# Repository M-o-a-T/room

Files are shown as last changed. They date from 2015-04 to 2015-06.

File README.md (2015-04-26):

# Room controller

Initially planned for controlling a radiator, this mutated into a generic
room controller schematic, featuring

* ATmega 168 controller
* two 1wire slave interfaces
* one I²C interface
* two 24V outputs
  * low-side switched
  * diode protected
  * PWM capable
* four binary I/O wires
  * with ADC, if required
* on-board programming interface
  * 6-pin version, accessible with pogo-pin adapter
* optional XTAL for 20 MHz operation
* WAGO connectors for the bus wires

The board fits standard round wall outlets. Its height is nominally 13mm
(determined by the WAGO 243 connectors).

## Who needs two 1wire interfaces?

The idea is that one is used for "slow" operations (parasitic-powered
thermometers, firmware updates (yes, I plan to do that)), while the other
bus does the "fast" stuff (run a CONDITIONAL SEARCH ten times a second).

## No 1wire master? Why?

Timing. You cannot run a 1wire master and slave at the same time.
Not reliably in software on one MCU, anyway.

If you want a master, you have I²C, connect an I²C-to-1wire interface.
(No, I didn't reserve space on the board for this.)

## Why 5V instead of 3.3V?

That would require me to run 1wire on 3.3V. It's possible, but you have
much less noise resistance. Also, the ATmega168 won't do 20 MHz on 3.3V.

That being said, running just the I²C on 3.3V isn't too difficult,
I'll add that if and when somebody actually needs it.

## How about software support?

The board will be fully supported by OWFS and the library at
https://github.com/M-o-a-T/owslave .

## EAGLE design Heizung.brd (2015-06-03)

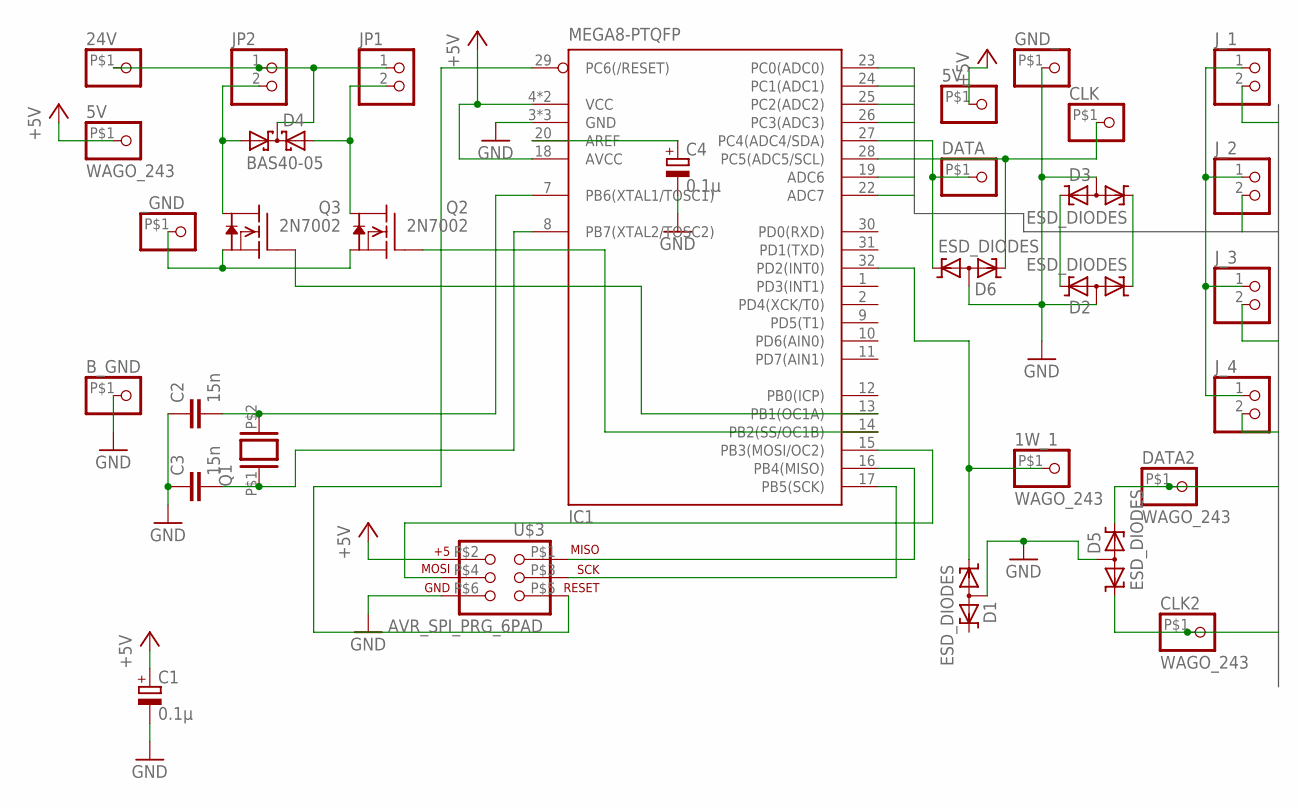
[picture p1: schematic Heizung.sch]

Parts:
1W_1, 5V, 5V_, 24V: WAGO_243
B_GND: WAGO_243
C1, C4: 0.1µ; CP1206
C2, C3: 15n; C0603
CLK, CLK2: WAGO_243
D1, D2, D3, D5, D6: ESD_DIODES; SOT23
D4: BAS40-05; SOT23
DATA, DATA2: WAGO_243
GND_: WAGO_243
IC1: MEGA8-PTQFP; TQFP32-08
JP1, JP2: PINHD-1X2LEVER; 1X02_GN
J_1, J_2, J_3, J_4: PINHD-1X2LEVER; 1X02_GN
Q1: XTALSMD5; Q_SMD5
Q2, Q3: 2N7002; SOT23
U$3: AVR_SPI_PRG_6PAD; 2X3_PAD
_GND: WAGO_243

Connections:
+5V: 5V.P$1, 5V_.P$1, C1.+, IC1.4 (VCC), IC1.6 (VCC), IC1.18 (AVCC), U$3.P$2 (2)
B1: D2.2 (K2), IC1.23 (PC0(ADC0)), J_1.2
B2: D2.1 (K1), IC1.24 (PC1(ADC1)), J_2.2
B3: D3.1 (K1), IC1.25 (PC2(ADC2)), J_3.2
B4: D3.2 (K2), IC1.26 (PC3(ADC3)), J_4.2
B5: D5.2 (K2), DATA2.P$1, IC1.19 (ADC6)
B6: CLK2.P$1, D5.1 (K1), IC1.22 (ADC7)
GND: B_GND.P$1, C1.-, C2.1, C3.1, C4.-, D1.3 (AA), D2.3 (AA), D3.3 (AA), D5.3 (AA), D6.3 (AA), GND_.P$1, IC1.3 (GND), IC1.5 (GND), IC1.21 (GND), J_1.1, J_2.1, J_3.1, J_4.1, U$3.P$6 (6)
GND24: Q2.2 (S), Q3.2 (S), _GND.P$1
unnamed: 24V.P$1, D4.3 (C), JP1.1, JP2.1
unnamed: IC1.14 (PB2(SS/OC1B)), Q2.1 (G)
unnamed: IC1.15 (PB3(MOSI/OC2)), U$3.P$4 (4)
unnamed: 1W_1.P$1, D1.1 (K1), IC1.32 (PD2(INT0))
unnamed: C2.2, IC1.7 (PB6(XTAL1/TOSC1)), Q1.P$2 (2)
unnamed: IC1.17 (PB5(SCK)), U$3.P$3 (3)
unnamed: D6.1 (K1), DATA.P$1, IC1.27 (PC4(ADC4/SDA))
unnamed: CLK.P$1, D6.2 (K2), IC1.28 (PC5(ADC5/SCL))
unnamed: D4.2 (A2), JP1.2, Q2.3 (D)
unnamed: C3.2, IC1.8 (PB7(XTAL2/TOSC2)), Q1.P$1 (1)
unnamed: D4.1 (A1), JP2.2, Q3.3 (D)
unnamed: IC1.16 (PB4(MISO)), U$3.P$1 (1)
unnamed: IC1.29 (PC6(/RESET)), U$3.P$5 (5)
unnamed: IC1.13 (PB1(OC1A)), Q3.1 (G)
unnamed: C4.+, IC1.20 (AREF)

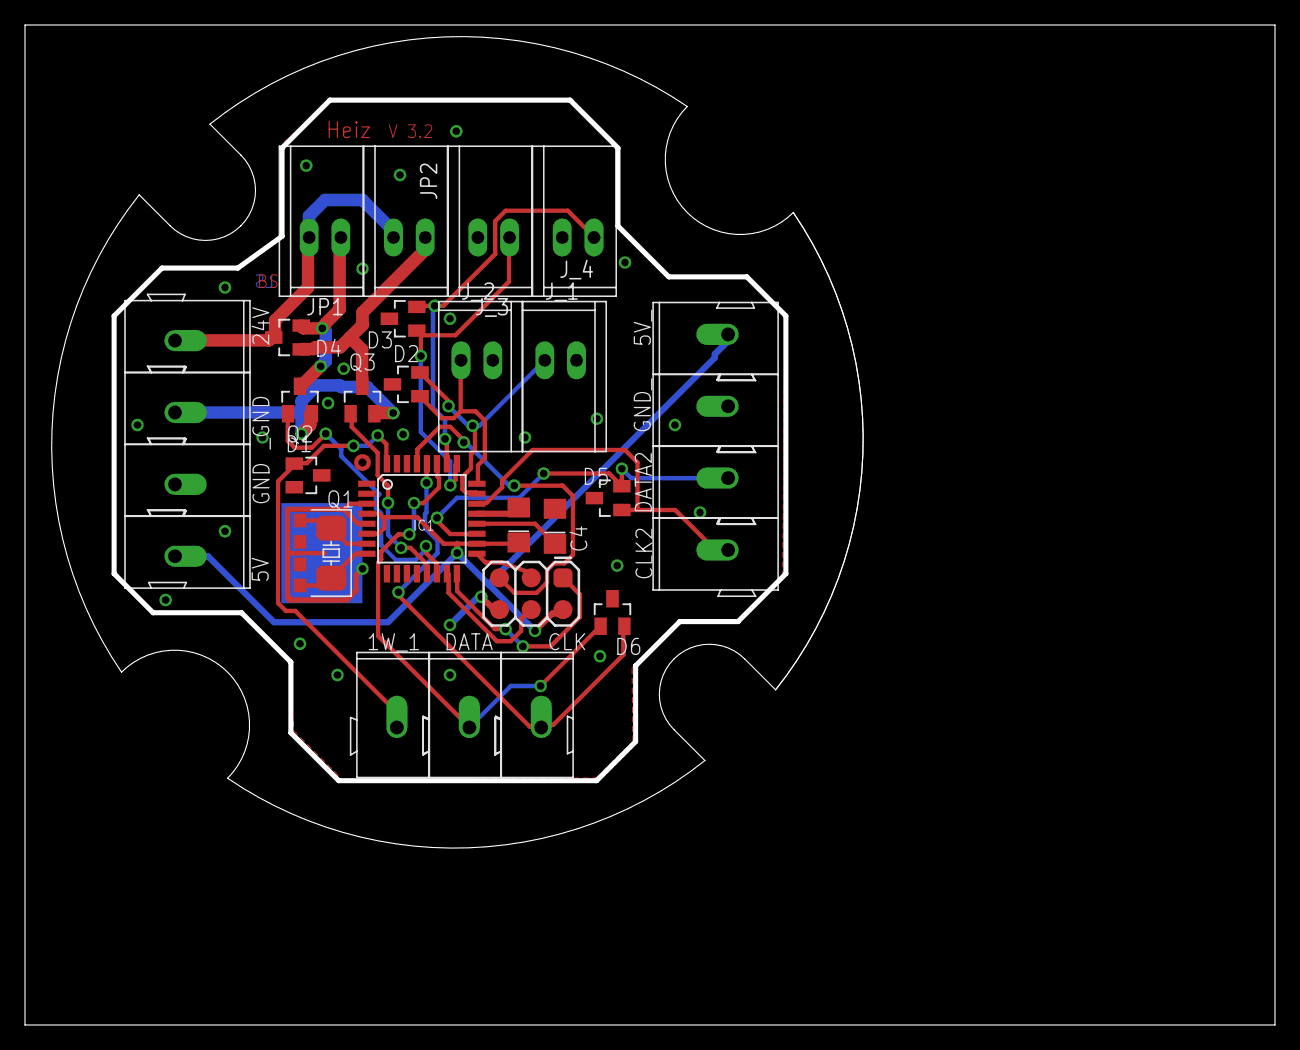
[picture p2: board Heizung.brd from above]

Board: 2 copper layers, 100.0 x 80.0 mm, 33 parts (0 on the bottom side), 24 nets.

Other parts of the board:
U$1: UNTERPUTZDOSE

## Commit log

2015-02-21 Heizungssteuerung V2
    Pullups am i2c
    [Heizung.brd, Heizung.sch]
2015-03-01 additional ground on power side, outline fixed
    [Heizung.brd, Heizung.sch]
2015-03-24 Update auf 2.4
    2-Draht-Klemmen verwendet und gedreht
    Wagoklemmen nach innen gedreht
    [Heizung.brd, Heizung.sch]
2015-03-24 Längere Pads für CPU
    [Heizung.brd, Heizung.sch]
2015-04-26 V2.7: add diode (for switching relays)
    general clean-up
    [Heizung.brd, Heizung.sch]
2015-04-26 change min width to 3.5mm, fix XTAL
    [Heizung.brd, Heizung.sch]
2015-04-26 Floating wires are bad for you
    [Heizung.brd, Heizung.sch]
2015-05-05 1x2 connectors wider, board outline more symmetric
    [Heizung.brd, Heizung.sch]
2015-05-11 V2.9
    add capacitor to AREF
    better routing
    [Heizung.brd, Heizung.sch]
2015-05-17 v3.0: use separate ground for switched power (24V)
    otherwise long cabling will raise ground too much
    [Heizung.brd, Heizung.sch]
2015-06-03 V 3.2: secondary I²C yes, secondary 1wire no
    [Heizung.brd, Heizung.sch]
